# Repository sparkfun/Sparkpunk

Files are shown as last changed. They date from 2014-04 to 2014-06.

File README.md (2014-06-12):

SparkPunk - 555-Based Sound Generator
========================================

Sparkpunk (https://www.sparkfun.com/products/11177)

The SparkPunk kit Is a simple synthesizer that you assemble yourself.  If you're into circuit bending, there are also a bunch of mods you can do to the board.

The [hookup guide](https://learn.sparkfun.com/tutorials/sparkpunk-hookup-guide) has instructions for assembly, and recommends the first few mods you can consider.

This kit was created in Eagle v6.5.0, with design simulations run in [LTSpice](http://www.linear.com/designtools/software/#LTspice). 

Repository Contents
-------------------

* **/Hardware** - All Eagle design files (.brd, .sch, .STL)
* **/Simulations** - LTSpice schematics for simulation

Product Versions
----------------
* [KIT-11177](https://www.sparkfun.com/products/11177)- SparkPunk Sound Generator kit.

Version History
---------------
* [92ca0f047e](https://github.com/sparkfun/Sparkpunk/commit/92ca0f047e3397d55f9d692a53f35f9b94eaf454) PCB revision 1.3 
* [d7b850879f](https://github.com/sparkfun/Sparkpunk/commit/d7b850879f343ff84054743f3793c951a8b04aeb) PCB revision 1.2 
* [14a08d87a8](https://github.com/sparkfun/Sparkpunk/commit/14a08d87a8a0a1159d9d88a0d402fd1dced95e91) PCB revision 1.1 
* [5d9a28e00b](https://github.com/sparkfun/Sparkpunk/commit/5d9a28e00b7679d7cc441decd9c348f060b642cb) PCB revision 1.0

License Information
-------------------
The hardware is released under [Creative Commons ShareAlike 4.0 International](https://creativecommons.org/licenses/by-sa/4.0/).
The code is beerware; if you see me (or any other SparkFun employee) at the local, and you've found our code helpful, please buy us a round!

Distributed as-is; no warranty is given.

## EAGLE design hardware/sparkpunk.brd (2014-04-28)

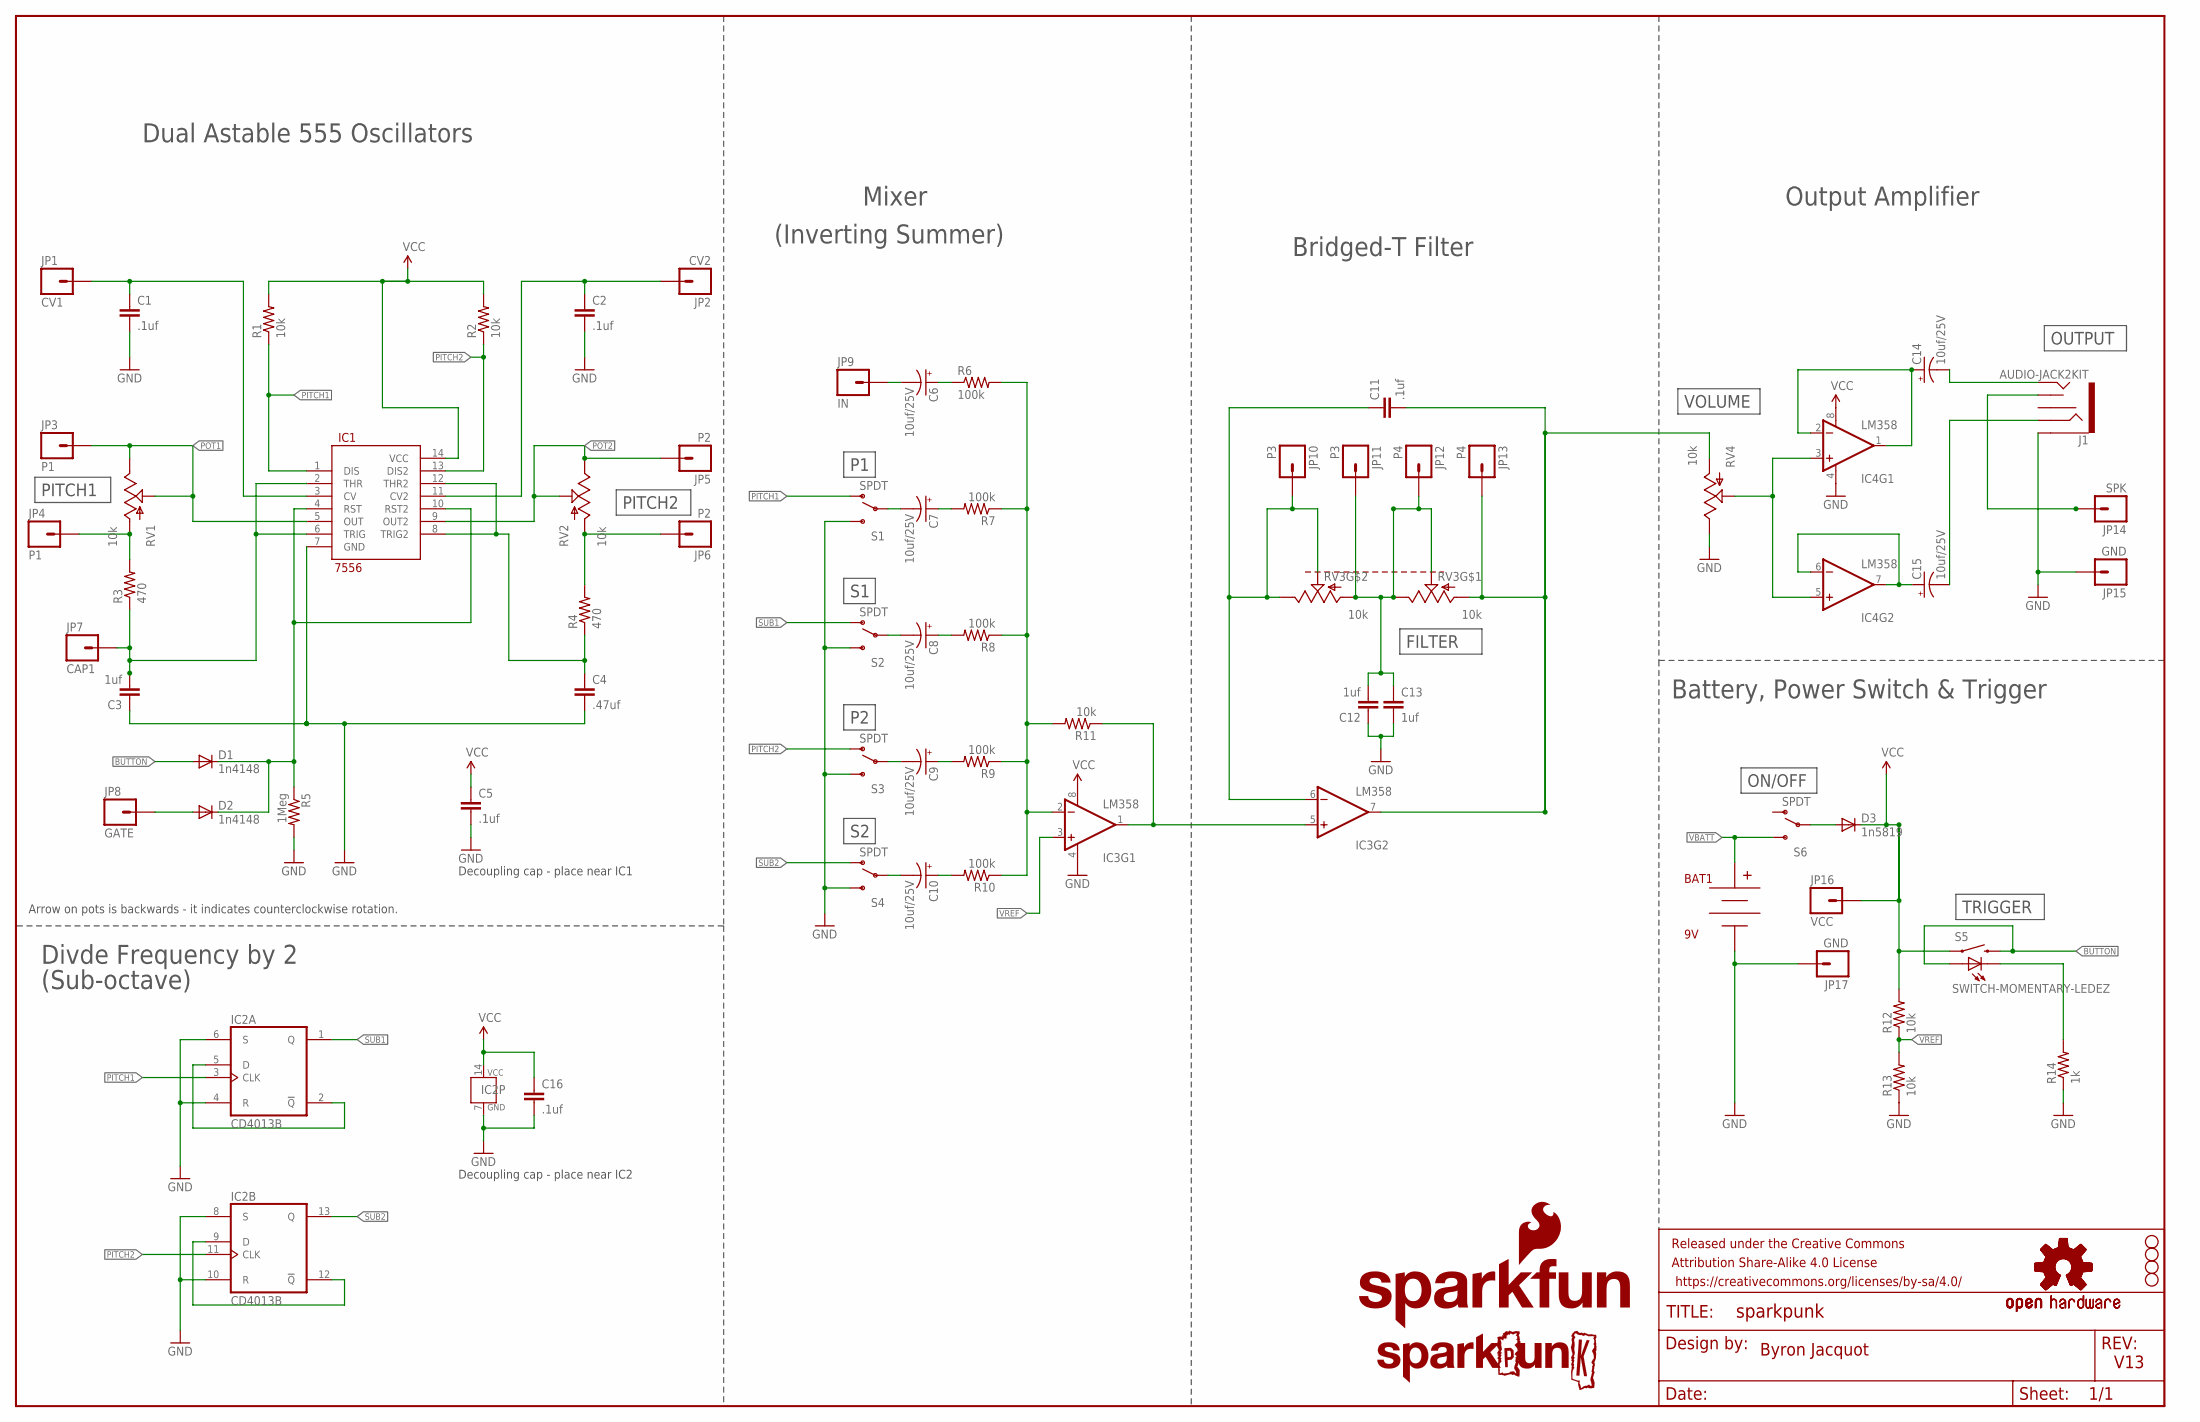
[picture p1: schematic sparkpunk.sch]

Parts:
BAT1: 9V; BC9VPC_KIT
C1, C2, C5, C11, C16: .1uf; CAP-PTH-SMALL-KIT
C3, C12, C13: 1uf; CAP-PTH-SMALL-KIT
C4: .47uf; CAP-PTH-SMALL-KIT
C6, C7, C8, C9, C10, C14, C15: 10uf/25V; CPOL-RADIAL-10UF-25V-KIT
D1, D2: 1n4148; DIODE-1N4148-KIT
D3: 1n5819; DIODE-1N4001-KIT
FRAME1: FRAME-LEDGER; CREATIVE_COMMONS
IC1: 7556; DIL14-KIT
IC2: CD4013B; DIL14-KIT
IC3, IC4: LM358; DIP08-KIT
J1: AUDIO-JACK2KIT; AUDIO-JACK-KIT
JP1: CV1; 1X01NS
JP2: CV2; 1X01NS
JP3, JP4: P1; 1X01NS
JP5, JP6: P2; 1X01NS
JP7: CAP1; 1X01NS
JP8: GATE; 1X01NS
JP9: IN; 1X01NS
JP10, JP11: P3; 1X01NS
JP12, JP13: P4; 1X01NS
JP14: SPK; 1X01NS
JP15, JP17: GND; 1X01NS
JP16: VCC; 1X01NS
LOGO1: SFE_LOGO_NAME_FLAME.2_INCH; SFE_LOGO_NAME_FLAME_.2
LOGO2: SPARKPUNK_LOGO.1INCH_TALL; SPARKPUNK_LOGO_.1
LOGO3, LOGO4: OSHW-LOGOM; OSHW-LOGO-M
R1, R2, R11, R12, R13: 10k; AXIAL-0.3EZ
R3, R4: 470; AXIAL-0.3EZ
R5: 1Meg; AXIAL-0.3EZ
R6, R7, R8, R9, R10: 100k; AXIAL-0.3EZ
R14: 1k; AXIAL-0.3EZ
RV1, RV2, RV4: 10k; ALPS_POT_KIT
RV3: 10k; POT_PANASONIC_DUAL_VERT_KIT
S1, S2, S3, S4, S6: SPDT; SWITCH-SPDT_KIT
S5: SWITCH-MOMENTARY-LEDEZ; TACTILE-PTH-LED-12MM-EZ
STANDOFF1, STANDOFF2, STANDOFF3, STANDOFF4: STAND-OFF

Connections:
BUTTON: D1.A, S5.2, S5.A
FILT-OUT: C11.2, IC3.7 (OUT), JP13.1, RV3.A3 (A), RV4.P$3 (A)
GND: BAT1.V-, C1.2, C2.2, C3.1, C4.2, C5.2, C12.1, C13.2, C16.2, IC1.7 (GND), IC2.4 (R), IC2.6 (S), IC2.7 (GND), IC2.8 (S), IC2.10 (R), IC3.4 (V-), IC4.4 (V-), J1.SLEEVE, JP15.1, JP17.1, R5.P$2 (2), R13.P$1 (1), R14.P$1 (1), RV4.P$1 (E), S1.3 (S), S2.3 (S), S3.3 (S), S4.3 (S)
N: IC4.3 (+IN), IC4.5 (+IN), RV4.P$2 (S)
unnamed: D2.A, JP8.1
unnamed: C4.1, IC1.8 (TRIG2), IC1.12 (THR2), R4.P$1 (1)
unnamed: D1.C, D2.C, IC1.4 (RST), IC1.10 (RST2), R5.P$1 (1)
unnamed: D3.A, S6.2
unnamed: JP6.1, R4.P$2 (2), RV2.P$3 (A)
unnamed: R14.P$2 (2), S5.C
unnamed: IC2.2 (!Q), IC2.5 (D)
unnamed: IC2.9 (D), IC2.12 (!Q)
unnamed: JP4.1, R3.P$2 (2), RV1.P$3 (A)
unnamed: C10.2 (-), S4.2
unnamed: J1.TSH, JP14.1
unnamed: C14.1 (+), IC4.1 (OUT), IC4.2 (-IN)
unnamed: C15.2 (-), J1.RING
unnamed: C10.1 (+), R10.P$2 (2)
unnamed: C9.1 (+), R9.P$2 (2)
unnamed: C9.2 (-), S3.2
unnamed: C6.2 (-), JP9.1
unnamed: C6.1 (+), R6.P$1 (1)
unnamed: C7.2 (-), S1.2
unnamed: C8.2 (-), S2.2
unnamed: C15.1 (+), IC4.6 (-IN), IC4.7 (OUT)
unnamed: IC3.2 (-IN), R6.P$2 (2), R7.P$1 (1), R8.P$1 (1), R9.P$1 (1), R10.P$1 (1), R11.P$2 (2)
unnamed: IC3.1 (OUT), IC3.5 (+IN), R11.P$1 (1)
unnamed: C8.1 (+), R8.P$2 (2)
unnamed: C7.1 (+), R7.P$2 (2)
unnamed: C14.2 (-), J1.TIP
unnamed: C11.1, IC3.6 (-IN), JP10.1, RV3.B1 (E), RV3.B2 (S)
unnamed: C12.2, C13.1, JP11.1, JP12.1, RV3.A1 (E), RV3.A2 (S), RV3.B3 (A)
PITCH1: IC1.1 (DIS), IC2.3 (CLK), R1.P$1 (1), S1.1 (O)
PITCH2: IC1.13 (DIS2), IC2.11 (CLK), R2.P$1 (1), S3.1 (O)
POT1: IC1.5 (OUT), JP3.1, RV1.P$1 (E), RV1.P$2 (S)
POT2: IC1.9 (OUT2), JP5.1, RV2.P$1 (E), RV2.P$2 (S)
SUB1: IC2.1 (Q), S2.1 (O)
SUB2: IC2.13 (Q), S4.1 (O)
VBATT: BAT1.V+, S6.3 (S)
VCAP1: C3.2, IC1.2 (THR), IC1.6 (TRIG), JP7.1, R3.P$1 (1)
VCC: C5.1, C16.1, D3.C, IC1.14 (VCC), IC2.14 (VCC), IC3.8 (V+), IC4.8 (V+), JP16.1, R1.P$2 (2), R2.P$2 (2), R12.P$2 (2), S5.4 (1)
VCC1: C2.1, IC1.11 (CV2), JP2.1
VCC2: C1.1, IC1.3 (CV), JP1.1
VREF: IC3.3 (+IN), R12.P$1 (1), R13.P$2 (2)

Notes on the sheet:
Byron Jacquot
V13
Arrow on pots is backwards - it indicates counterclockwise rotation.
Battery, Power Switch & Trigger
Dual Astable 555 Oscillators
Divde Frequency by 2
(Sub-octave)
Mixer
(Inverting Summer)
Bridged-T Filter
Output Amplifier
PITCH1
PITCH2
FILTER
VOLUME
OUTPUT
TRIGGER
Decoupling cap - place near IC1
Decoupling cap - place near IC2
ON/OFF

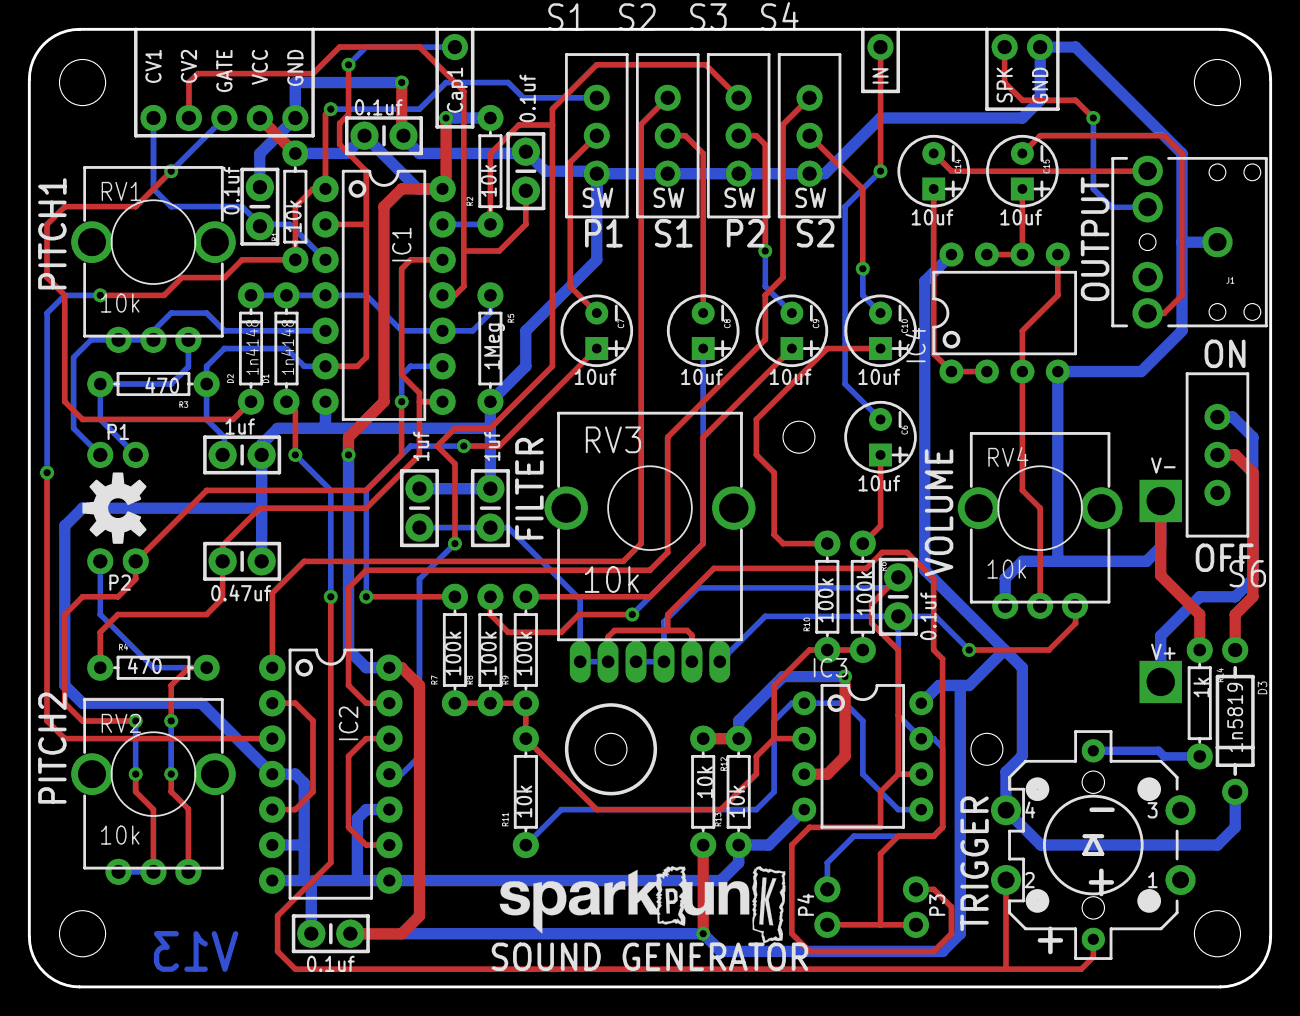
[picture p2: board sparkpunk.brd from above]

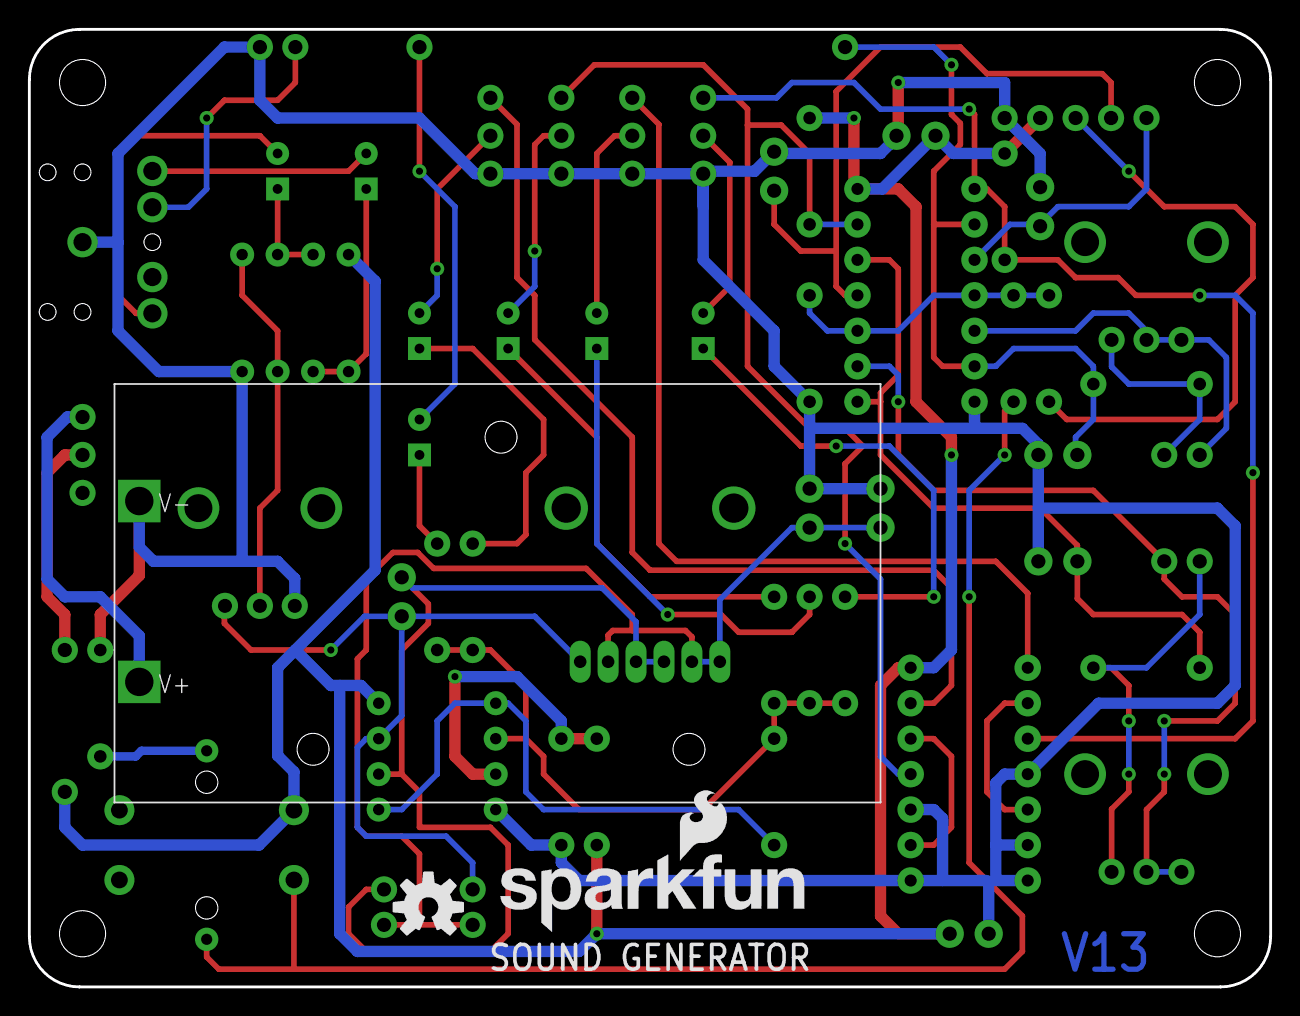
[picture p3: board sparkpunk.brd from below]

Board: 2 copper layers, 88.9 x 68.6 mm, 75 parts (3 on the bottom side), 44 nets.

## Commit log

2013-11-26 Adding board files
    [sparkpunk.brd, sparkpunk.sch]
2013-12-02 Updates following group review
    [sparkpunk.brd, sparkpunk.sch]
2013-12-26 Updates from prototype evaluation
    [sparkpunk.brd, sparkpunk.sch]
2013-12-26 Updating sparkpunk parts with in-house ID#s
    [sparkpunk.brd, sparkpunk.sch]
2013-12-26 One more sparkle part number.
    [sparkpunk.brd, sparkpunk.sch]
2014-03-25 Adding intermediate simulations.
    Piecemeal sims of mixer, filter comparison, etc.
2014-03-25 PCB update
    Redesigned some aspects of PCB, for tighter integration with the
    sequencer.
    [sparkpunk.brd, sparkpunk.sch]
2014-04-25 Updated with feedback from beta builders.
    [sparkpunk.brd, sparkpunk.sch]
2014-04-28 Ready for Reds
    Reviewed and ready to go.
    [sparkpunk.brd]
2014-06-12 Adding oscillator sim.
    Found oscillator sim on my desktop, and updated it to represent the
    actual device.

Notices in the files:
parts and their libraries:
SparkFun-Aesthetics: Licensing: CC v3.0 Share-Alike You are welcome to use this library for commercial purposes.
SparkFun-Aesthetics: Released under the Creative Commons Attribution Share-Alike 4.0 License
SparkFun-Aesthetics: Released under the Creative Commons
